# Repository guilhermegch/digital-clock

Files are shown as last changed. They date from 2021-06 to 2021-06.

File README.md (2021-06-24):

# Digital clock #

This is a crystal based clock is made using only common ICs: 
- Binary Counter (CD4020, CD4017, 74HC393)
- AND gates (74HC08)
- NAND gates (CD4093)
- Multiplexer (74HC251)
- 7 segments display decoder (CD4511)

## How it works ##

This clock source is on a 32.768 kHz crystal. The signal is amplified by the NAND gates and sent to a frequency divider. Since 32786 = 2^15, we use the CD4020 14 stages with the output cascaded to a CD4017, so we have a stable 1 Hz oscillator. 

The 2048 Hz (Q3) and the 64 Hz (Q8) clocks are used by the fast and slow clock adjusts. Send the three signals into a multiplexer, and the clock signal goes to the 74HC393 counter that, combined with AND gates, makes the logic circuit. 

In the end, the counter stage numbers feed a binary to seven segment display decoder.

The seconds are counted in binary by the LEDs. Above the displays is the decimal. The displays show the hours in the 24h format, the Brazilian standard.

The PCB size is 100 x 100 mm, to feat on the promotional range of Chinese manufactures, like [PCBWay](https://www.pcbway.com) and [JLCPCB](https://jlcpcb.com).

Feel free to change the project to meet your needs.

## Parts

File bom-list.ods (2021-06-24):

BOM LIST
DESCRIPTION | QUANTITY | REFERENCE | PART NUMBER
5mm WARM WHITE DIFFUSED LED | 8 | D7-D14 | BL-L513UW2W
8-INPUT MULTIPLEXER 74HC251 | 1 | U5 | SN74HC251N
BCD-TO-7-SEGMENT LATCH DECODER DRIVERS 4511 | 4 | U11,U13,U15,U17 | CD4511BE
CERAMIC CAPACITOR 22pF | 2 | C3, C4 | MCCHU5220J5
COMMON-CATHODE SINGLE DIGIT 7 SEGMENT DISPLAY | 4 | U12, U14, U16, U18 | 5611AH
CRYSTAL 32.756 kHz | 1 | Y1 | LFXTAL002995Bulk
DC JACK 5.5mm x 2.1mm | 1 | J1 | CON-SOCJ-2155
DECADE COUNTER 4017 | 1 | U4 | CD4017BE
DUAL 4-BIT BINARY RIPPLE COUNTER 74HC393 | 3 | U6,U9,U10 | SN74HC393N
FAST SWITCHING SIGNAL DIODE 1N4148 | 6 | D1-D6 | 1N4148
POLYESTER CAPACITOR 100nF | 10 | C2, C5-C13 | 2A104J
POLYESTER CAPACITOR 330nF | 1 | C1 | B32529C0334K000
POSITIVE VOLTAGE REGULATOR 7805 | 1 | U1 | L7805CV
QUAD 2 INPUT AND GATE 74HC08 | 2 | U7,U8 | SN74HC08N
QUAD 2 INPUT NAND SCHMITT TRIGGER 4093 | 1 | U2 | CD4093BE
RESISTOR 10k 1/4W | 10 | R2-R11 | CF1/4CT52R103J
RESISTOR 10M 1/4W | 1 | R1 | CF14JA10M0
RESISTOR 470R 1/4W | 36 | R12-R47 | CF14JT470R
RIPPLE-CARRY BINARY COUNTER 4020 | 1 | U3 | HFC4020BE, CD4020BE
TACTILE SWITCH 6mm | 2 | SW1,SW2 | SKHHBWA010

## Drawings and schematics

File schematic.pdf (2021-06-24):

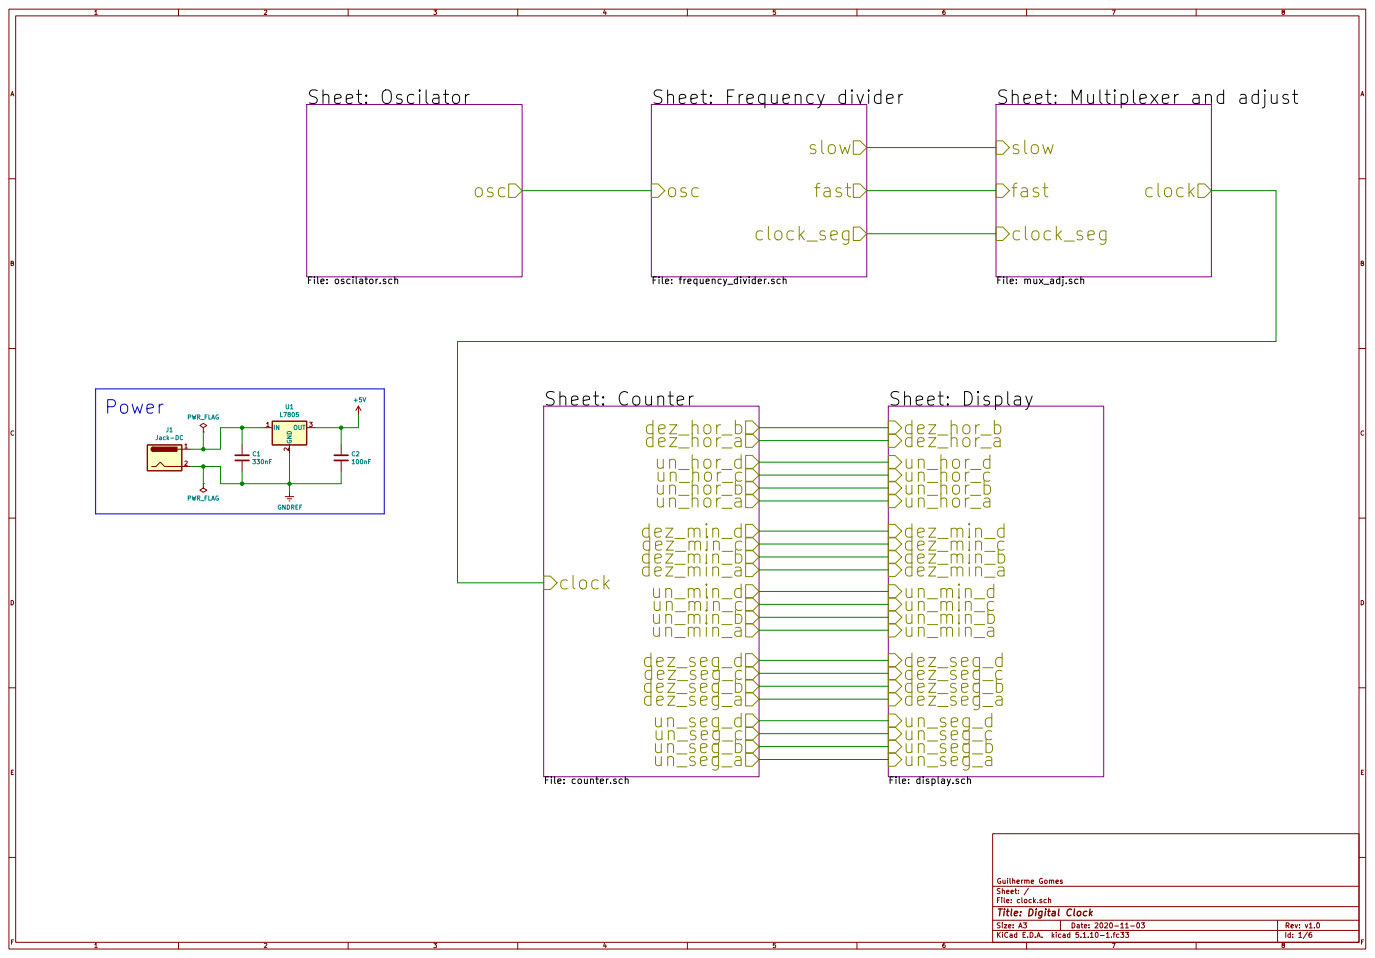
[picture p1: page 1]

Sheet: Multiplexer and adjust

Id: 1/6 Title: Digital Clock

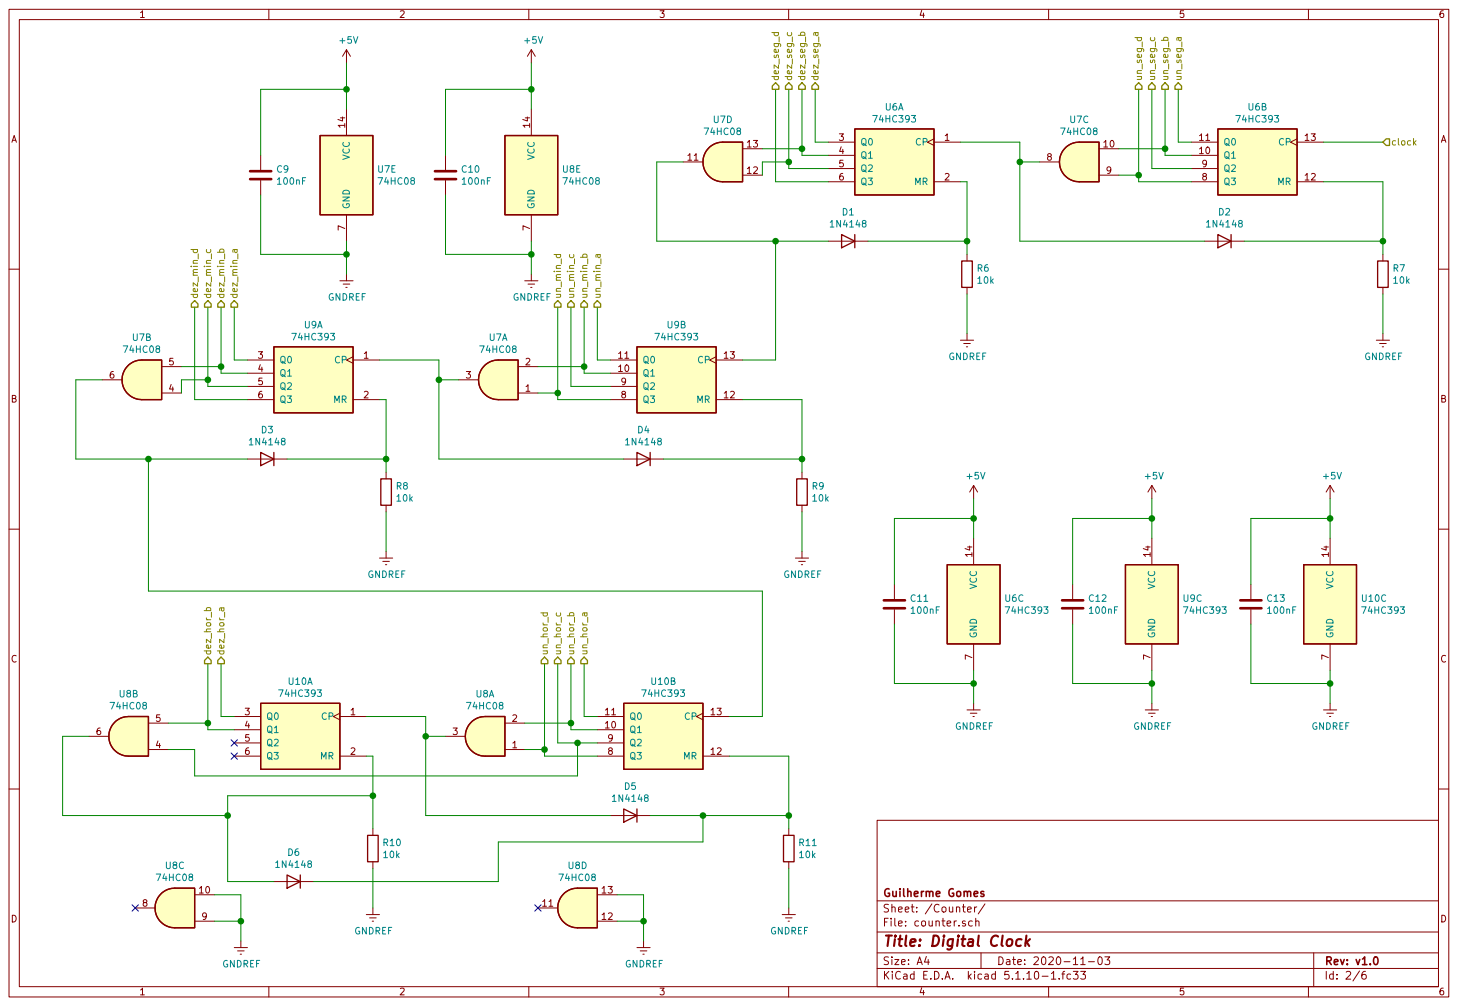
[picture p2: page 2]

File: counter.sch Sheet: /Counter/ Guilherme Gomes

Id: 2/6 Title: Digital Clock

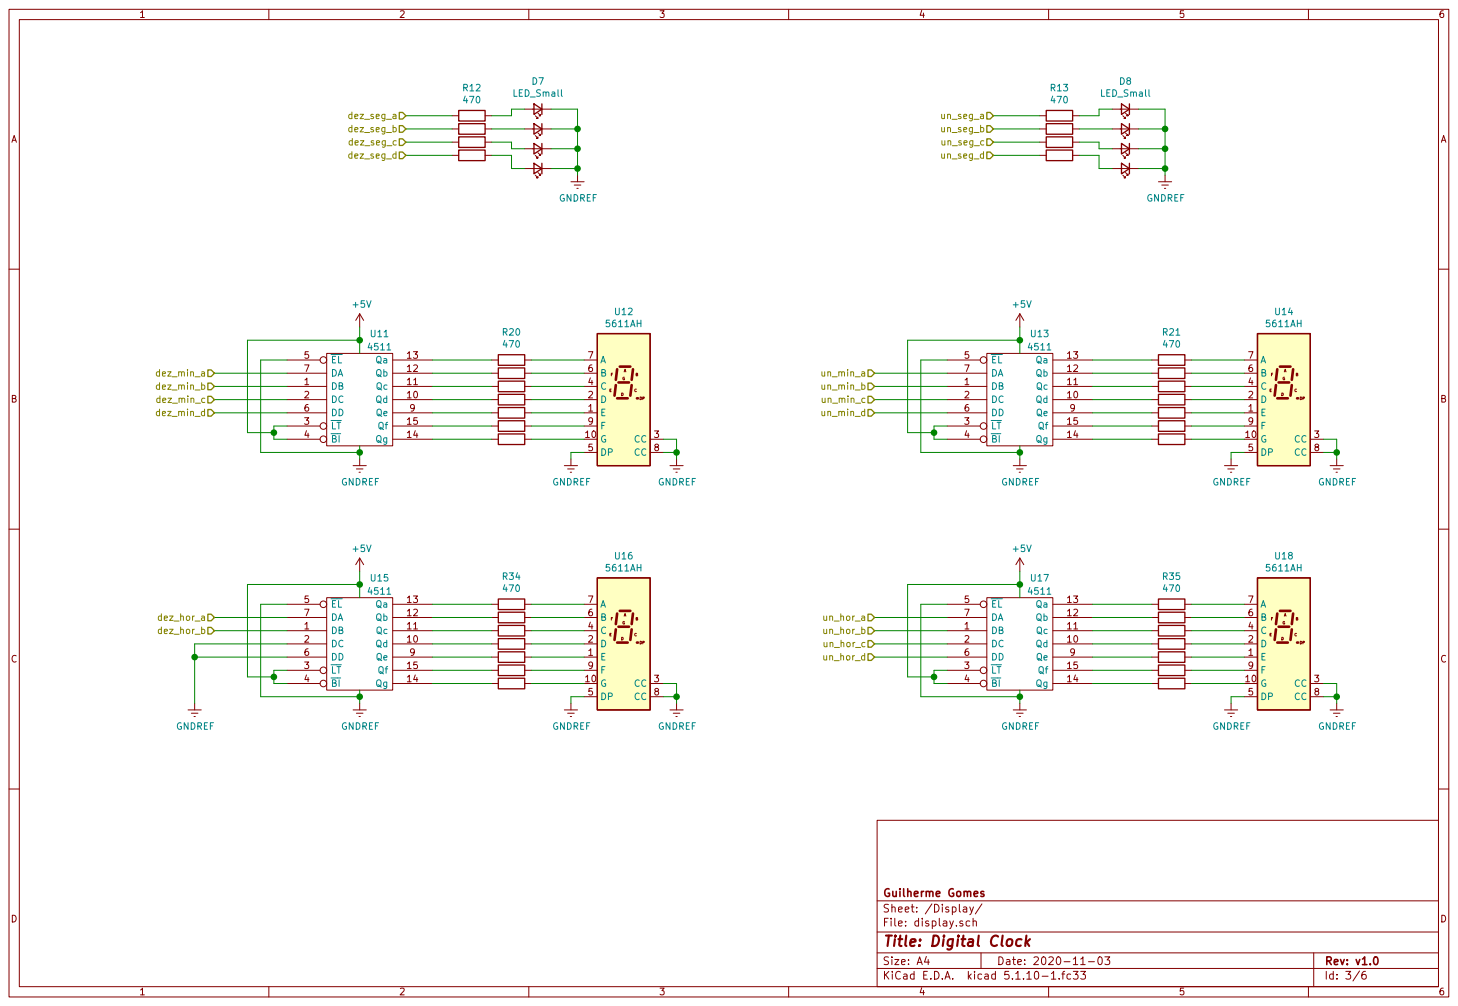
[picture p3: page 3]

File: display.sch
Id: 3/6 Title: Digital Clock

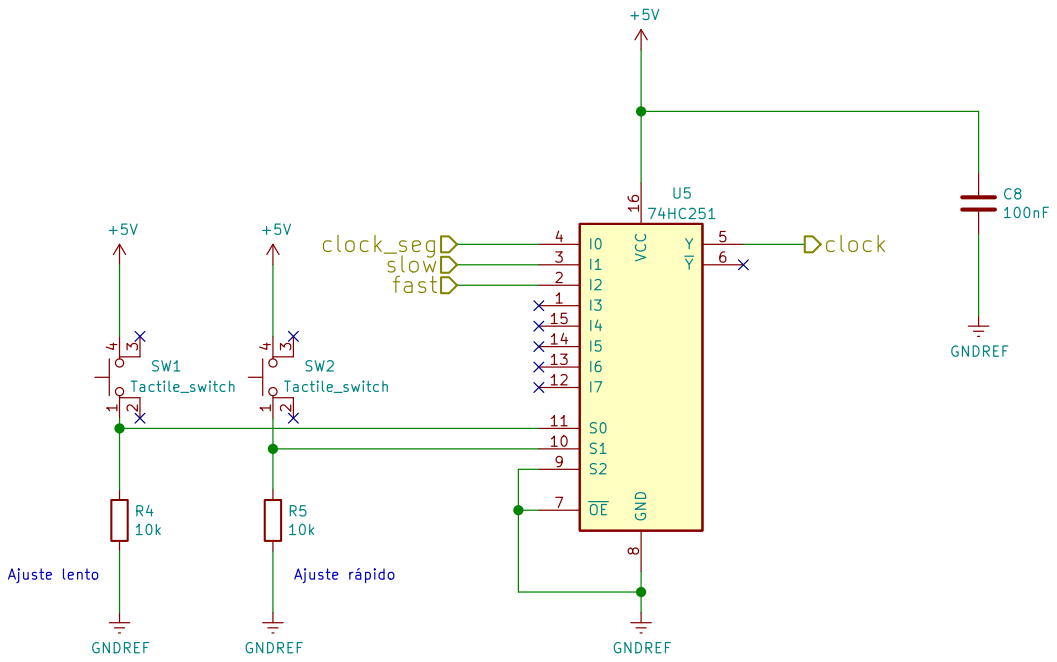
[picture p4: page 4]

File: mux_adj.sch
Id: 4/6 Title: Digital Clock

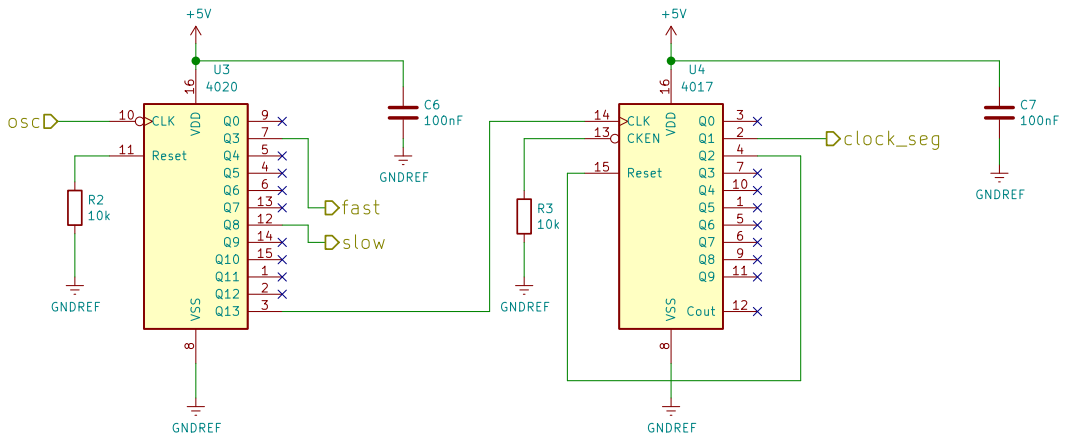
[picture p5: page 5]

Sheet: /Frequency divider/ Guilherme Gomes GNDREF

File: frequency_divider.sch
Id: 5/6 Title: Digital Clock

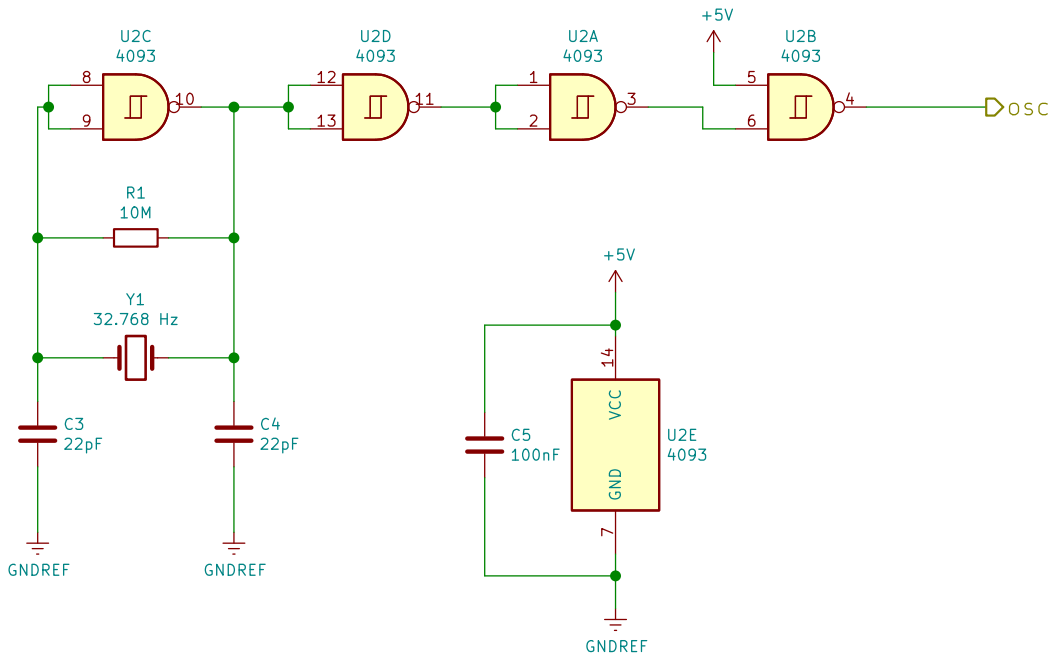
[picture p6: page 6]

File: oscilator.sch Sheet: /Oscilator/ Guilherme Gomes

Id: 6/6 Title: Digital Clock

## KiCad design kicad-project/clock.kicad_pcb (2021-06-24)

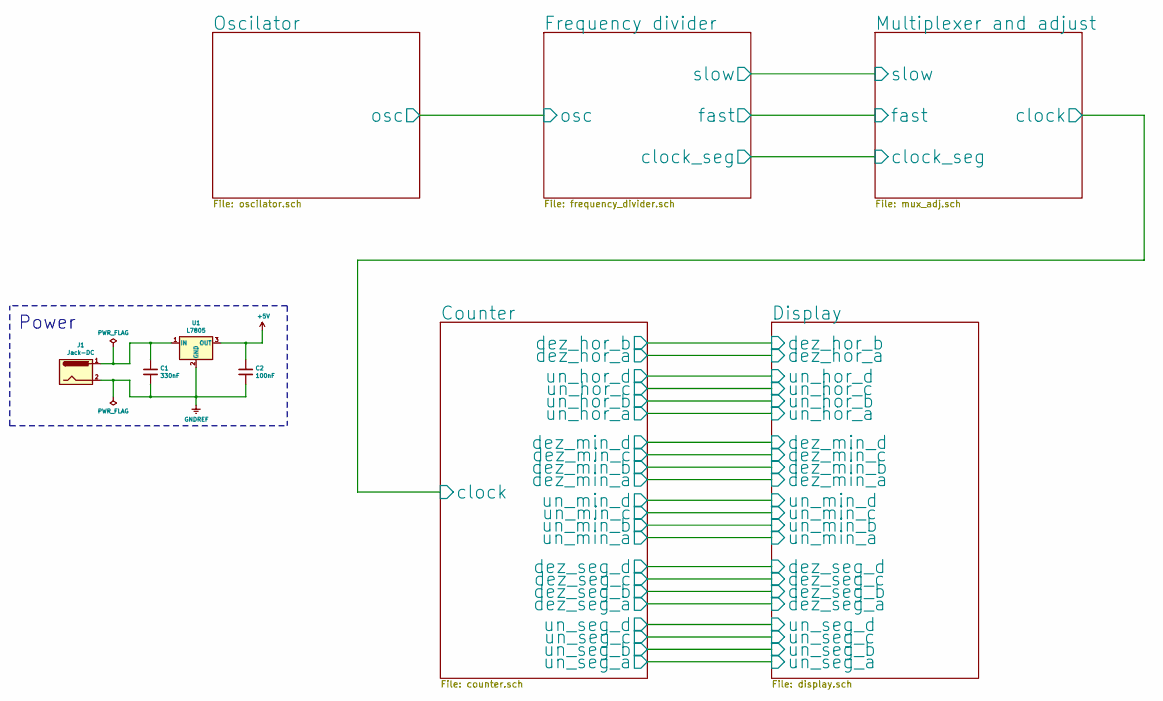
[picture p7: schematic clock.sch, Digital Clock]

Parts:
C1: 330nF; C_Rect_L7.0mm_W2.5mm_P5.00mm
C2: 100nF; C_Disc_D9.0mm_W5.0mm_P7.50mm
J1: Jack-DC; BarrelJack_Horizontal
U1: L7805; TO-220-3_Vertical

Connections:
+5V: C2.1, U1.3 (OUT); also elsewhere on the board
GNDREF: C1.2, C2.2, J1.2, U1.2 (GND); also elsewhere on the board
unnamed: C1.1, J1.1, U1.1 (IN)

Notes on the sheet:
Power

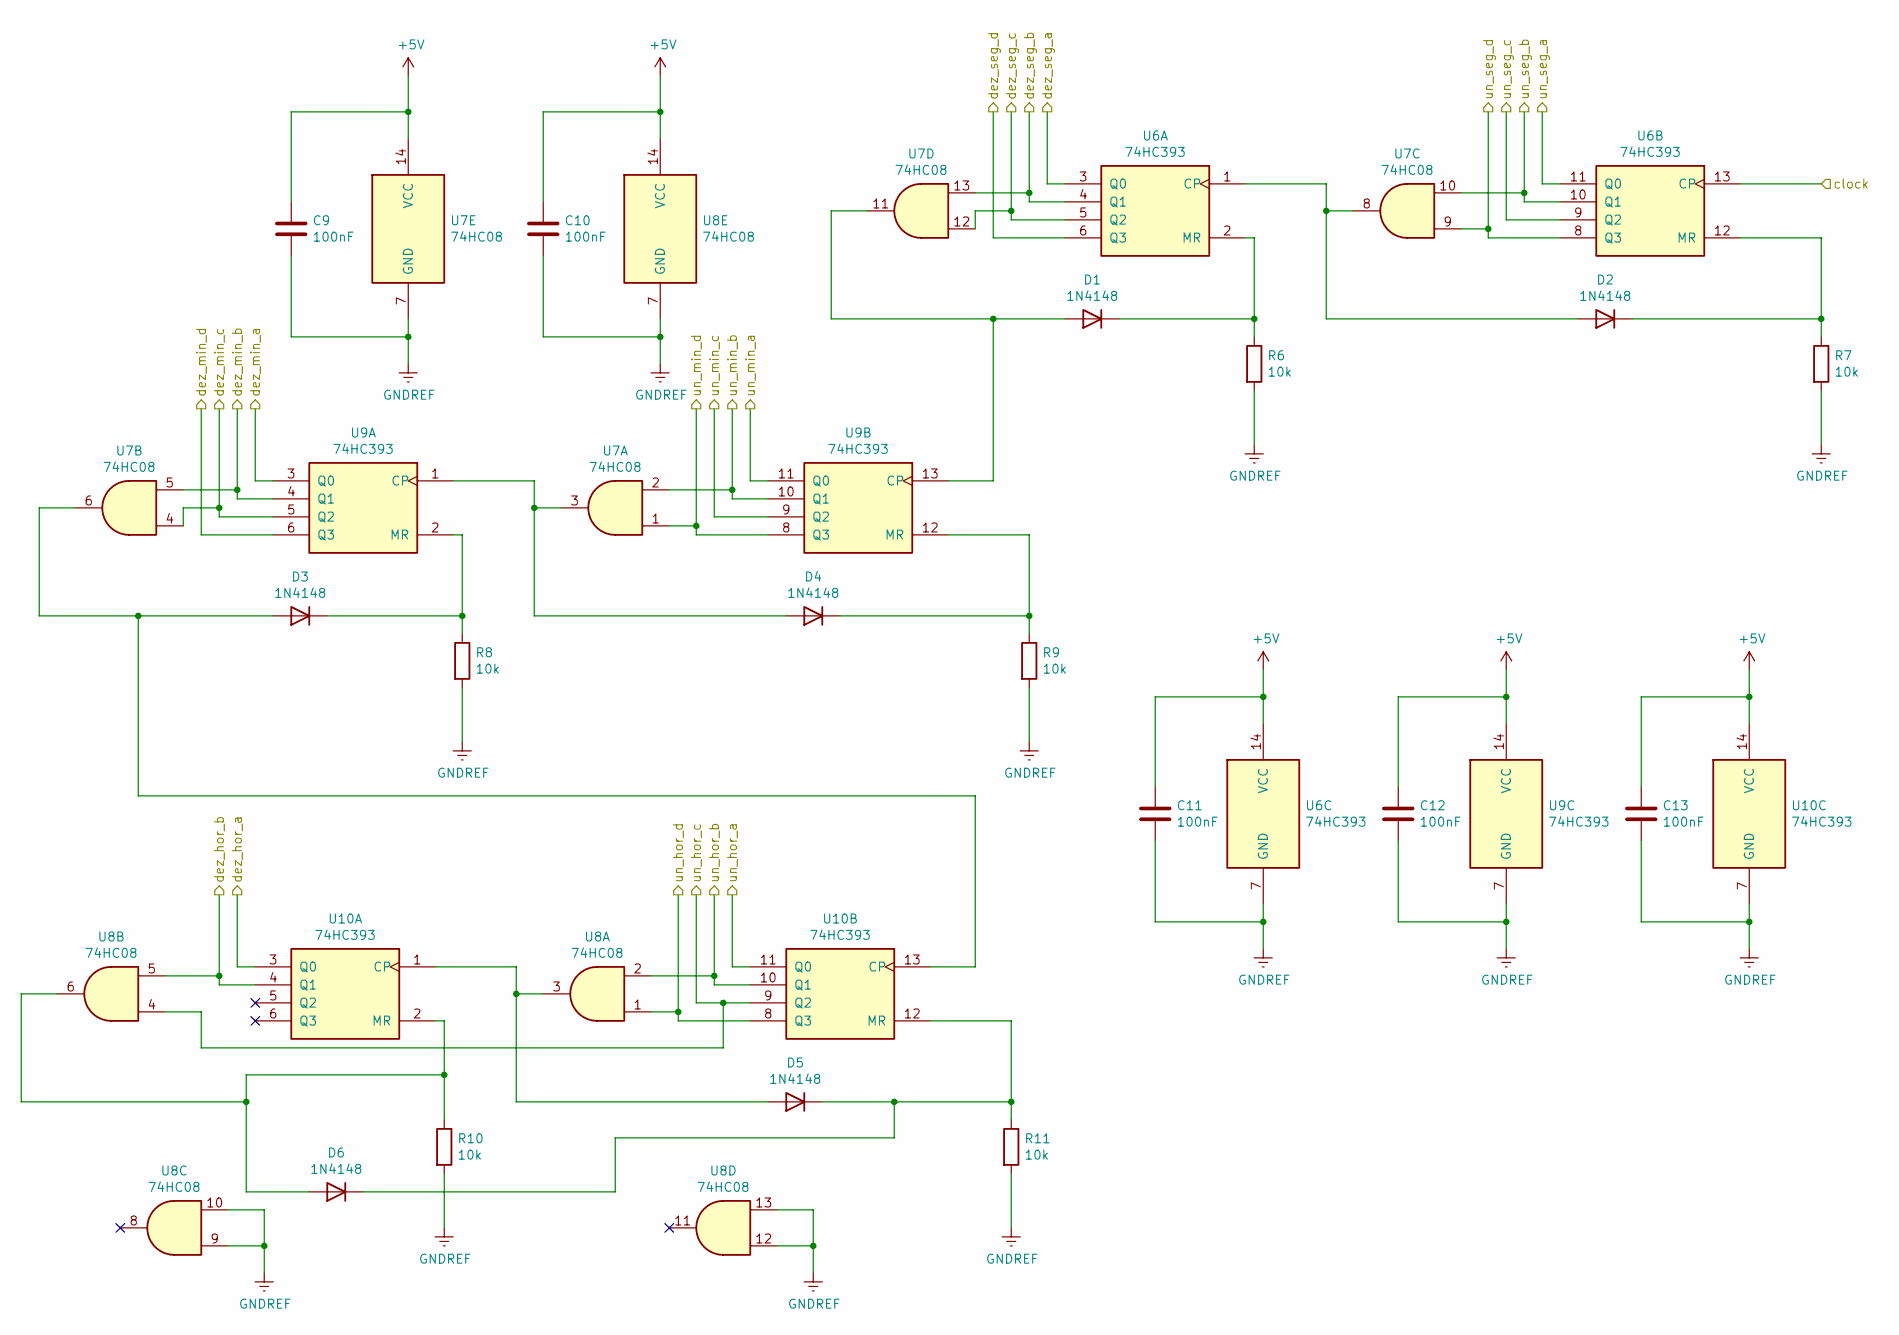
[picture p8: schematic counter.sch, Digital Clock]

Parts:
C9, C10, C11, C12, C13: 100nF; C_Disc_D9.0mm_W5.0mm_P7.50mm
D1, D2, D3, D4, D5, D6: 1N4148; D_DO-35_SOD27_P7.62mm_Horizontal
R6, R7, R8, R9, R10, R11: 10k; R_Axial_DIN0204_L3.6mm_D1.6mm_P7.62mm_Horizontal
U6, U9, U10: 74HC393; DIP-14_W7.62mm_Socket_LongPads
U7, U8: 74HC08; DIP-14_W7.62mm_Socket_LongPads

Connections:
+5V: C9.1, C10.1, C11.1, C12.1, C13.1, U6.14 (VCC), U7.14 (VCC), U8.14 (VCC), U9.14 (VCC), U10.14 (VCC); also elsewhere on the board
/Contador/clock: U6.13 (CP); also elsewhere on the board
/Contador/dez_hor_a: U10.3 (Q0); also elsewhere on the board
/Contador/dez_hor_b: U8.5, U10.4 (Q1); also elsewhere on the board
/Contador/dez_min_a: U9.3 (Q0); also elsewhere on the board
/Contador/dez_min_b: U7.5, U9.4 (Q1); also elsewhere on the board
/Contador/dez_min_c: U7.4, U9.5 (Q2); also elsewhere on the board
/Contador/dez_min_d: U9.6 (Q3); also elsewhere on the board
/Contador/dez_seg_a: U6.3 (Q0); also elsewhere on the board
/Contador/dez_seg_b: U6.4 (Q1), U7.13; also elsewhere on the board
/Contador/dez_seg_c: U6.5 (Q2), U7.12; also elsewhere on the board
/Contador/dez_seg_d: U6.6 (Q3); also elsewhere on the board
/Contador/un_hor_a: U10.11 (Q0); also elsewhere on the board
/Contador/un_hor_b: U8.2, U10.10 (Q1); also elsewhere on the board
/Contador/un_hor_c: U8.4, U10.9 (Q2); also elsewhere on the board
/Contador/un_hor_d: U8.1, U10.8 (Q3); also elsewhere on the board
/Contador/un_min_a: U9.11 (Q0); also elsewhere on the board
/Contador/un_min_b: U7.2, U9.10 (Q1); also elsewhere on the board
/Contador/un_min_c: U9.9 (Q2); also elsewhere on the board
/Contador/un_min_d: U7.1, U9.8 (Q3); also elsewhere on the board
/Contador/un_seg_a: U6.11 (Q0); also elsewhere on the board
/Contador/un_seg_b: U6.10 (Q1), U7.10; also elsewhere on the board
/Contador/un_seg_c: U6.9 (Q2); also elsewhere on the board
/Contador/un_seg_d: U6.8 (Q3), U7.9; also elsewhere on the board
GNDREF: C9.2, C10.2, C11.2, C12.2, C13.2, R6.2, R7.2, R8.2, R9.2, R10.2, R11.2, U6.7 (GND), U7.7 (GND), U8.7 (GND), U8.9, U8.10, U8.12, U8.13, U9.7 (GND), U10.7 (GND); also elsewhere on the board
unnamed: D1.1 (K), R6.1, U6.2 (MR)
unnamed: D1.2 (A), U7.11, U9.13 (CP)
unnamed: D2.1 (K), R7.1, U6.12 (MR)
unnamed: D2.2 (A), U6.1 (CP), U7.8
unnamed: D3.1 (K), R8.1, U9.2 (MR)
unnamed: D3.2 (A), U7.6, U10.13 (CP)
unnamed: D4.1 (K), R9.1, U9.12 (MR)
unnamed: D4.2 (A), U7.3, U9.1 (CP)
unnamed: D5.1 (K), D6.1 (K), R11.1, U10.12 (MR)
unnamed: D5.2 (A), U8.3, U10.1 (CP)
unnamed: D6.2 (A), R10.1, U8.6, U10.2 (MR)

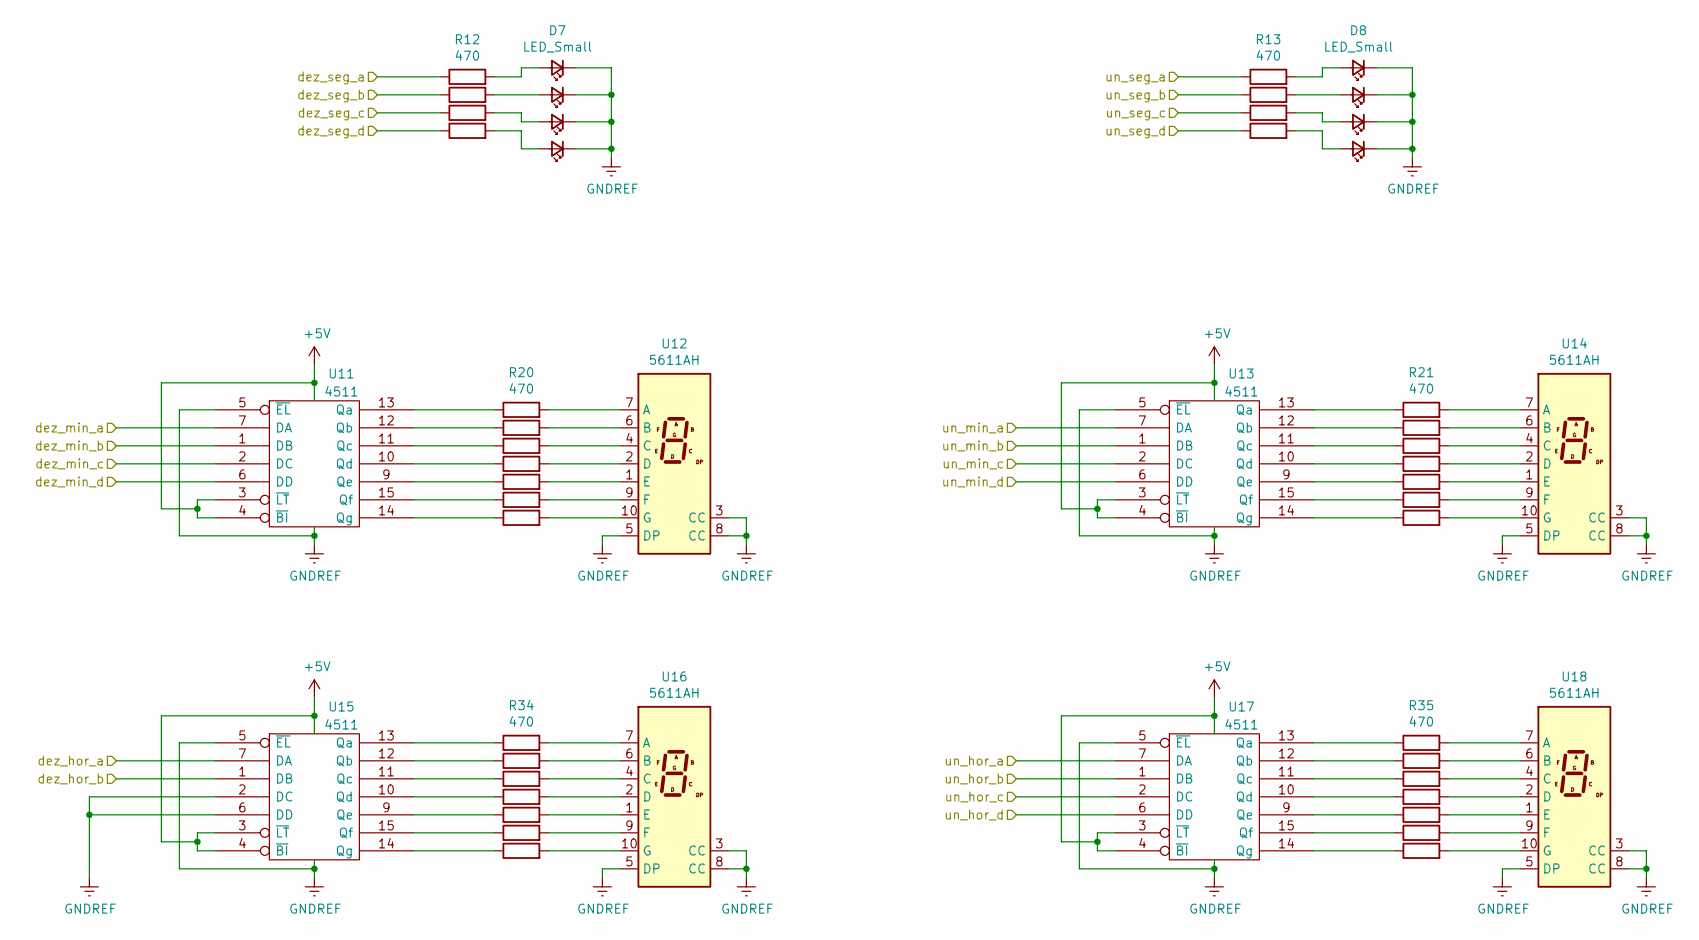
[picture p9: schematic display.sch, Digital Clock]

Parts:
D7, D8, D9, D10, D11, D12, D13, D14: LED_Small; LED_D5.0mm
R12, R13, R14, R15, R16, R17, R18, R19, R20, R21, R22, R23, R24, R25, R26, R27, R28, R29, R30, R31, R32, R33, R34, R35, R36, R37, R38, R39, R40, R41, R42, R43, R44, R45, R46, R47: 470; R_Axial_DIN0204_L3.6mm_D1.6mm_P7.62mm_Horizontal
U11, U13, U15, U17: 4511; DIP-16_W7.62mm_Socket_LongPads
U12, U14, U16, U18: 5611AH; D1X8K

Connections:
+5V: U11.3 (~LT), U11.4 (~BI), U11.16 (Vdd), U13.3 (~LT), U13.4 (~BI), U13.16 (Vdd), U15.3 (~LT), U15.4 (~BI), U15.16 (Vdd), U17.3 (~LT), U17.4 (~BI), U17.16 (Vdd); also elsewhere on the board
/Contador/dez_hor_a: U15.7 (DA); also elsewhere on the board
/Contador/dez_hor_b: U15.1 (DB); also elsewhere on the board
/Contador/dez_min_a: U11.7 (DA); also elsewhere on the board
/Contador/dez_min_b: U11.1 (DB); also elsewhere on the board
/Contador/dez_min_c: U11.2 (DC); also elsewhere on the board
/Contador/dez_min_d: U11.6 (DD); also elsewhere on the board
/Contador/dez_seg_a: R12.1; also elsewhere on the board
/Contador/dez_seg_b: R14.1; also elsewhere on the board
/Contador/dez_seg_c: R16.1; also elsewhere on the board
/Contador/dez_seg_d: R18.1; also elsewhere on the board
/Contador/un_hor_a: U17.7 (DA); also elsewhere on the board
/Contador/un_hor_b: U17.1 (DB); also elsewhere on the board
/Contador/un_hor_c: U17.2 (DC); also elsewhere on the board
/Contador/un_hor_d: U17.6 (DD); also elsewhere on the board
/Contador/un_min_a: U13.7 (DA); also elsewhere on the board
/Contador/un_min_b: U13.1 (DB); also elsewhere on the board
/Contador/un_min_c: U13.2 (DC); also elsewhere on the board
/Contador/un_min_d: U13.6 (DD); also elsewhere on the board
/Contador/un_seg_a: R13.1; also elsewhere on the board
/Contador/un_seg_b: R15.1; also elsewhere on the board
/Contador/un_seg_c: R17.1; also elsewhere on the board
/Contador/un_seg_d: R19.1; also elsewhere on the board
GNDREF: D7.1 (K), D8.1 (K), D9.1 (K), D10.1 (K), D11.1 (K), D12.1 (K), D13.1 (K), D14.1 (K), U11.5 (~EL), U11.8 (Vss), U12.3 (CC), U12.5 (DP), U12.8 (CC), U13.5 (~EL), U13.8 (Vss), U14.3 (CC), U14.5 (DP), U14.8 (CC), U15.2 (DC), U15.5 (~EL), U15.6 (DD), U15.8 (Vss), U16.3 (CC), U16.5 (DP), U16.8 (CC), U17.5 (~EL), U17.8 (Vss), U18.3 (CC), U18.5 (DP), U18.8 (CC); also elsewhere on the board
unnamed: D7.2 (A), R12.2
unnamed: D8.2 (A), R13.2
unnamed: D9.2 (A), R14.2
unnamed: D10.2 (A), R15.2
unnamed: D11.2 (A), R16.2
unnamed: D12.2 (A), R17.2
unnamed: D13.2 (A), R18.2
unnamed: D14.2 (A), R19.2
unnamed: R20.1, U11.13 (Qa)
unnamed: R20.2, U12.7 (A)
unnamed: R21.1, U13.13 (Qa)
unnamed: R21.2, U14.7 (A)
unnamed: R22.1, U11.12 (Qb)
unnamed: R22.2, U12.6 (B)
unnamed: R23.1, U13.12 (Qb)
unnamed: R23.2, U14.6 (B)
unnamed: R24.1, U11.11 (Qc)
unnamed: R24.2, U12.4 (C)
unnamed: R25.1, U13.11 (Qc)
unnamed: R25.2, U14.4 (C)
unnamed: R26.1, U11.10 (Qd)
unnamed: R26.2, U12.2 (D)
unnamed: R27.1, U13.10 (Qd)
unnamed: R27.2, U14.2 (D)
unnamed: R28.1, U11.9 (Qe)
unnamed: R28.2, U12.1 (E)
unnamed: R29.1, U13.9 (Qe)
unnamed: R29.2, U14.1 (E)
unnamed: R30.1, U11.15 (Qf)
unnamed: R30.2, U12.9 (F)
unnamed: R31.1, U13.15 (Qf)
unnamed: R31.2, U14.9 (F)
unnamed: R32.1, U11.14 (Qg)
unnamed: R32.2, U12.10 (G)
unnamed: R33.1, U13.14 (Qg)
unnamed: R33.2, U14.10 (G)
unnamed: R34.1, U15.13 (Qa)
unnamed: R34.2, U16.7 (A)
unnamed: R35.1, U17.13 (Qa)
unnamed: R35.2, U18.7 (A)
unnamed: R36.1, U15.12 (Qb)
unnamed: R36.2, U16.6 (B)
unnamed: R37.1, U17.12 (Qb)
unnamed: R37.2, U18.6 (B)
unnamed: R38.1, U15.11 (Qc)
unnamed: R38.2, U16.4 (C)
unnamed: R39.1, U17.11 (Qc)
unnamed: R39.2, U18.4 (C)
unnamed: R40.1, U15.10 (Qd)
unnamed: R40.2, U16.2 (D)
unnamed: R41.1, U17.10 (Qd)
unnamed: R41.2, U18.2 (D)
unnamed: R42.1, U15.9 (Qe)
unnamed: R42.2, U16.1 (E)
unnamed: R43.1, U17.9 (Qe)
unnamed: R43.2, U18.1 (E)
unnamed: R44.1, U15.15 (Qf)
unnamed: R44.2, U16.9 (F)
unnamed: R45.1, U17.15 (Qf)
unnamed: R45.2, U18.9 (F)
unnamed: R46.1, U15.14 (Qg)
unnamed: R46.2, U16.10 (G)
unnamed: R47.1, U17.14 (Qg)
unnamed: R47.2, U18.10 (G)

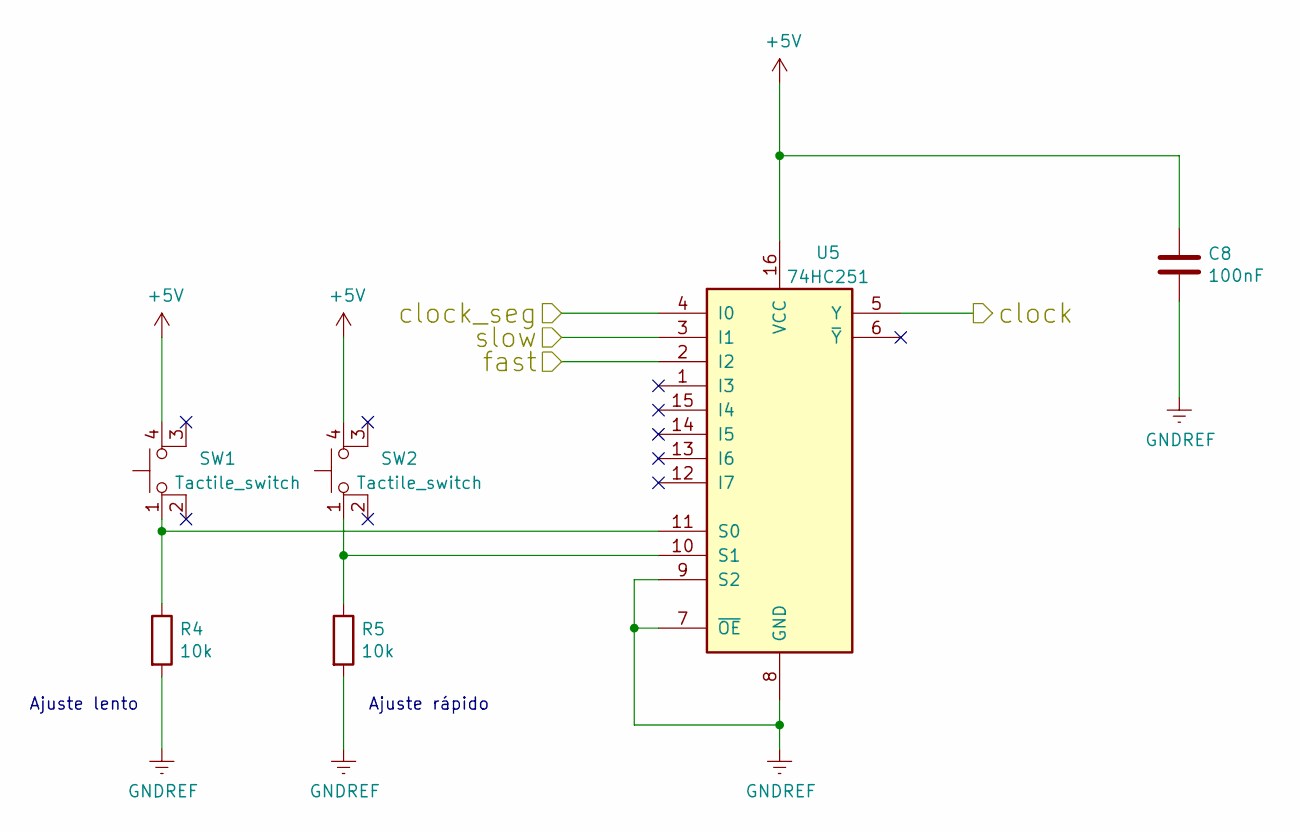
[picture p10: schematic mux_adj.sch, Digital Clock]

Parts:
C8: 100nF; C_Disc_D9.0mm_W5.0mm_P7.50mm
R4, R5: 10k; R_Axial_DIN0204_L3.6mm_D1.6mm_P7.62mm_Horizontal
SW1, SW2: Tactile_switch; SW_PUSH_6mm_H5mm
U5: 74HC251; DIP-16_W7.62mm_Socket_LongPads

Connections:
+5V: C8.1, SW1.4 (A), SW2.4 (A), U5.16 (VCC); also elsewhere on the board
/Contador/clock: U5.5 (Y); also elsewhere on the board
/Divisor de frequência/clock_seg: U5.4 (I0); also elsewhere on the board
/Divisor de frequência/fast: U5.2 (I2); also elsewhere on the board
/Divisor de frequência/slow: U5.3 (I1); also elsewhere on the board
GNDREF: C8.2, R4.2, R5.2, U5.7 (~OE), U5.8 (GND), U5.9 (S2); also elsewhere on the board
unnamed: R4.1, SW1.1, U5.11 (S0)
unnamed: R5.1, SW2.1, U5.10 (S1)

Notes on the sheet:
Ajuste lento
Ajuste rápido

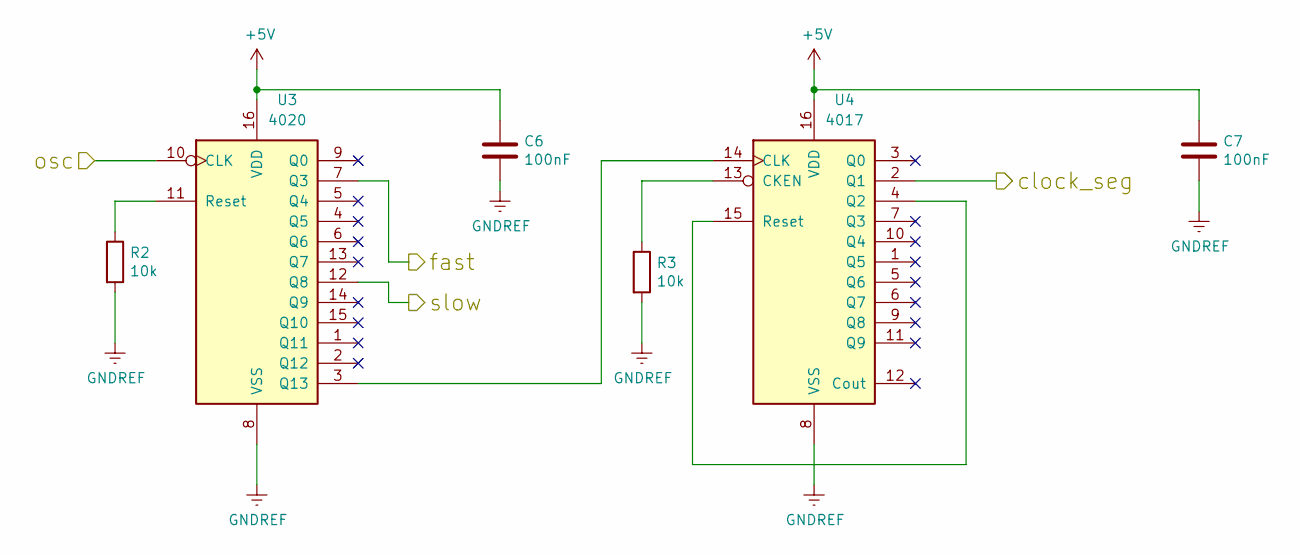
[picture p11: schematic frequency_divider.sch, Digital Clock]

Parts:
C6, C7: 100nF; C_Disc_D9.0mm_W5.0mm_P7.50mm
R2, R3: 10k; R_Axial_DIN0204_L3.6mm_D1.6mm_P7.62mm_Horizontal
U3: 4020; DIP-16_W7.62mm_Socket_LongPads
U4: 4017; DIP-16_W7.62mm_Socket_LongPads

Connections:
+5V: C6.1, C7.1, U3.16 (VDD), U4.16 (VDD); also elsewhere on the board
/Divisor de frequência/clock_seg: U4.2 (Q1); also elsewhere on the board
/Divisor de frequência/fast: U3.7 (Q3); also elsewhere on the board
/Divisor de frequência/osc: U3.10 (CLK); also elsewhere on the board
/Divisor de frequência/slow: U3.12 (Q8); also elsewhere on the board
GNDREF: C6.2, C7.2, R2.2, R3.2, U3.8 (VSS), U4.8 (VSS); also elsewhere on the board
unnamed: R2.1, U3.11 (Reset)
unnamed: R3.1, U4.13 (CKEN)
unnamed: U3.3 (Q13), U4.14 (CLK)
unnamed: U4.4 (Q2), U4.15 (Reset)

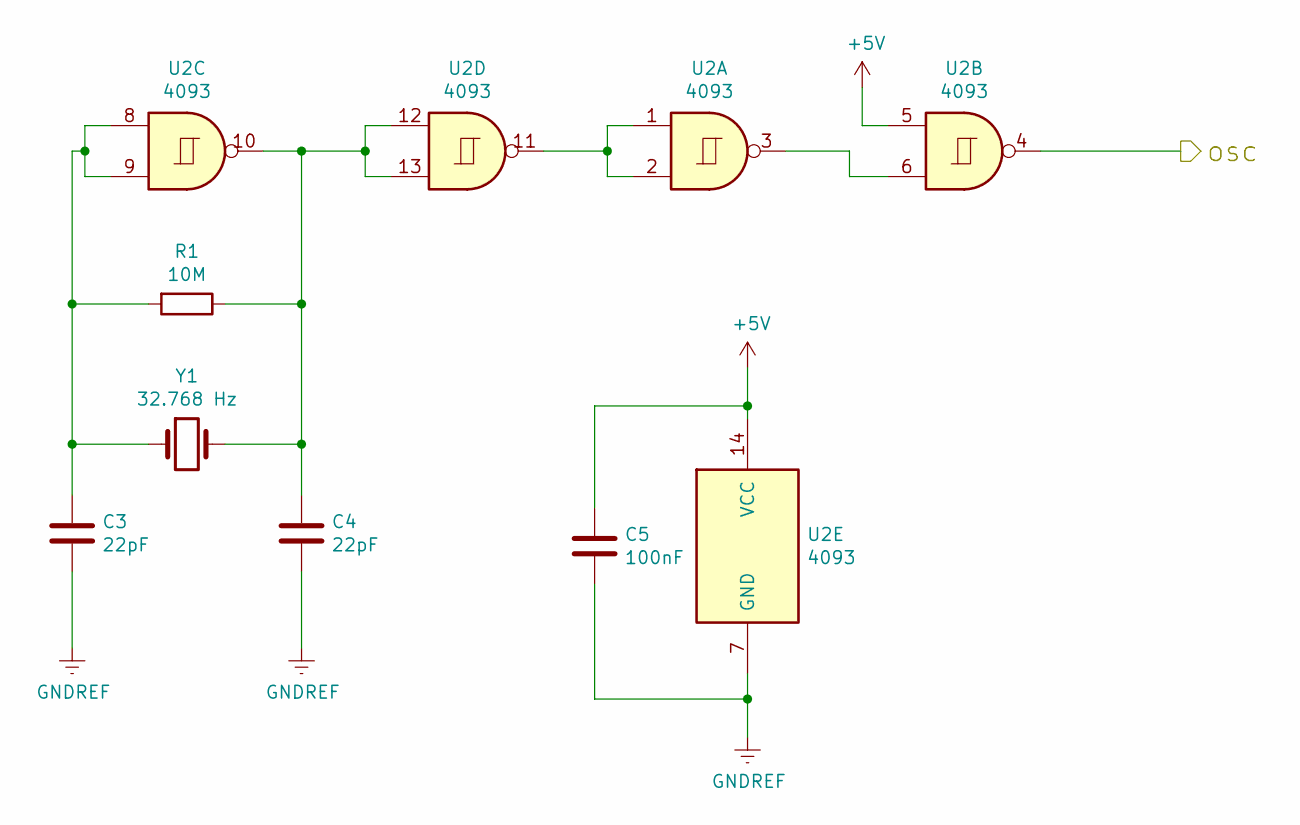
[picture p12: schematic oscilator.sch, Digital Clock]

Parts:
C3, C4: 22pF; C_Disc_D3.0mm_W2.0mm_P2.50mm
C5: 100nF; C_Disc_D9.0mm_W5.0mm_P7.50mm
R1: 10M; R_Axial_DIN0204_L3.6mm_D1.6mm_P7.62mm_Horizontal
U2: 4093; DIP-14_W7.62mm_Socket_LongPads
Y1: 32.768 Hz; Crystal_Round_D3.0mm_Vertical

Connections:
+5V: C5.1, U2.5, U2.14 (VCC); also elsewhere on the board
/Divisor de frequência/osc: U2.4; also elsewhere on the board
GNDREF: C3.2, C4.2, C5.2, U2.7 (GND); also elsewhere on the board
unnamed: C3.1, R1.2, U2.8, U2.9, Y1.1
unnamed: C4.1, R1.1, U2.10, U2.12, U2.13, Y1.2
unnamed: U2.1, U2.2, U2.11
unnamed: U2.3, U2.6

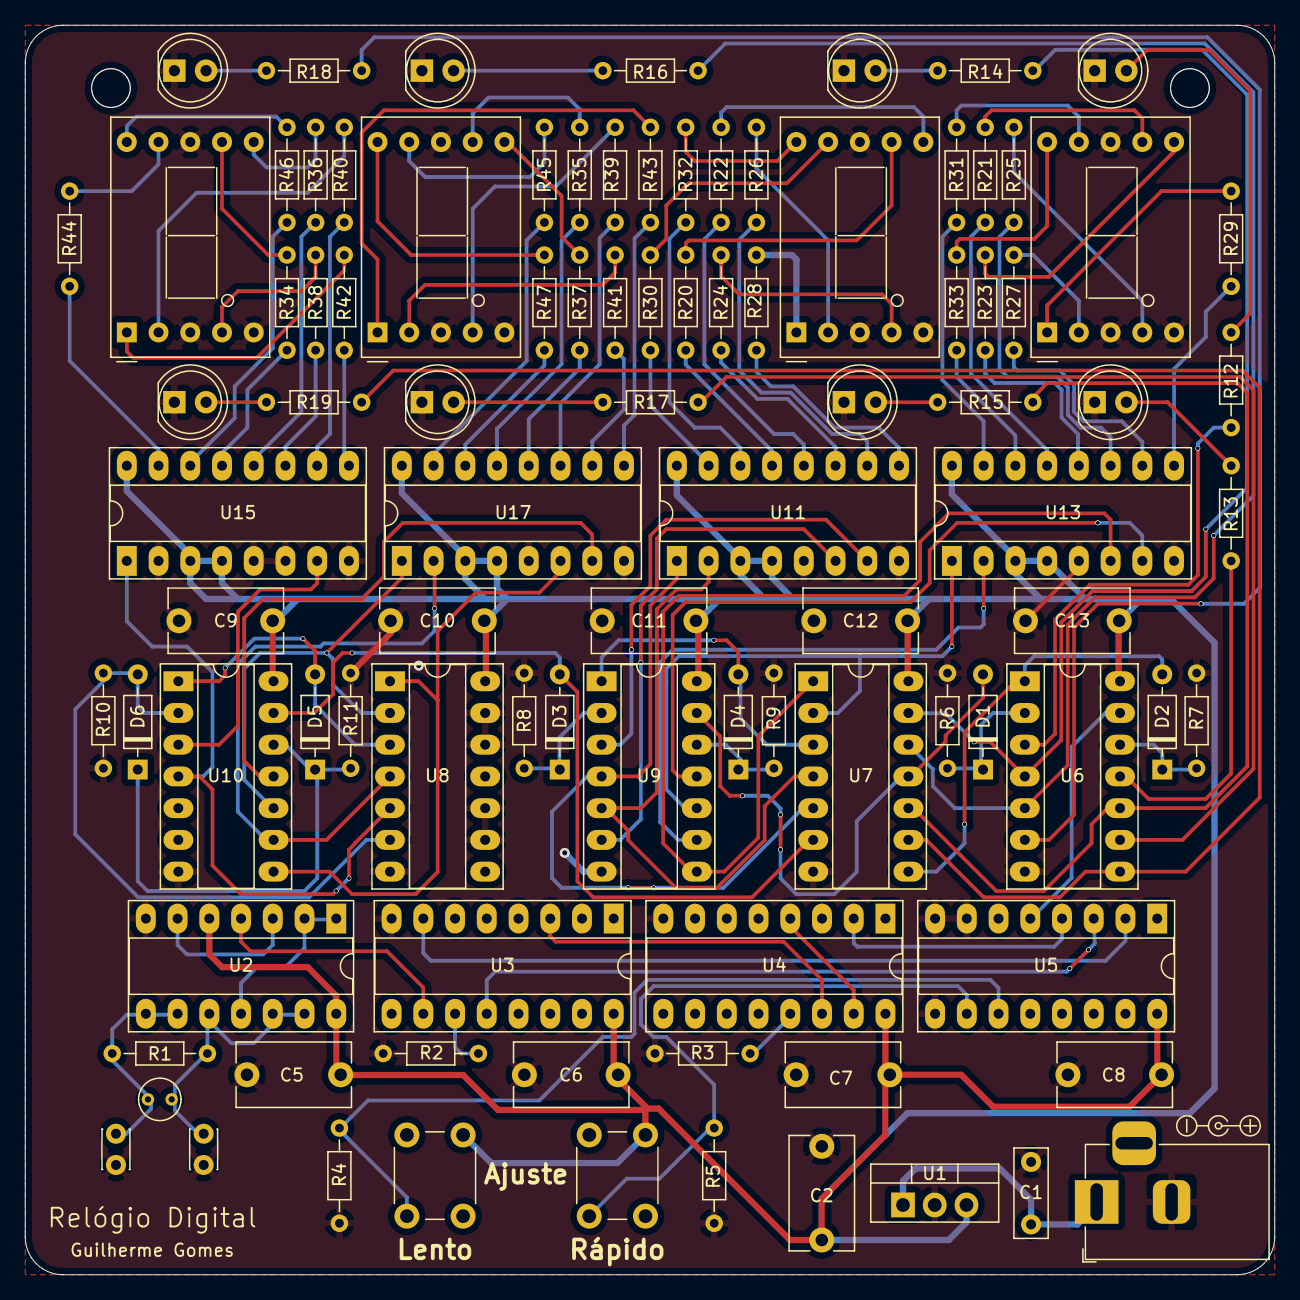
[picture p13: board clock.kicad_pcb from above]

Board: 2 copper layers, 100.0 x 100.0 mm, 96 parts (0 on the bottom side), 115 nets.

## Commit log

2021-06-24 Adding BOM list
    [bom-list.ods]
2021-06-24 Adding the project schematic
2021-06-24 Adding the KiCAD project
    [clock.kicad_pcb, clock.sch, counter.sch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]
2021-06-24 Adding the Gerber files
    [Relógio-B_Cu.gbr, Relógio-B_Mask.gbr, Relógio-B_Paste.gbr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]
